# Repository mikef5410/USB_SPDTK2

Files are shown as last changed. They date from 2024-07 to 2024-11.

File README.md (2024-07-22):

## USB_SPDTK (KiCAD)

USB control of two standard microwave SPDT coax switches. This is the KiCAD re-work for JLCPCB assembly.

Related projects: [my USB Dual SPDT project](https://github.com/mikef5410/USB_SPDT)  and  [the software for these projects](https://github.com/mikef5410/USB_Attenuator_Switch_Stacklight)

# Project setup

The software is included here as a git submodule. After cloning, do a
`git submodule init` followed by `git submodule update --recursive`

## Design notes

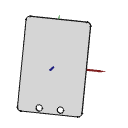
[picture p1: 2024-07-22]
thumbnails/Thumbnail.png

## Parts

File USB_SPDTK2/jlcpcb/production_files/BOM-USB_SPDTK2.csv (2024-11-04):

Comment | Designator | Footprint | LCSC | Quantity
4.7u | C19,C5,C7 | C_0402_1005Metric_Pad0.74x0.62mm_HandSolder | C106859 | 3
MMZ1608Y102B | FB1 | C_0603_1608Metric_Pad1.08x0.95mm_HandSolder | C114771 | 1
SW_Push | SW1,SW2 | SW_Tactile_SPST_NO_Straight_CK_PTS636Sx25SMTRLFS | C118141 | 2
13.3k | R5 | R_0402_1005Metric_Pad0.72x0.64mm_HandSolder | C122547 | 1
GRN | D7 | LED_0603_1608Metric_Pad1.05x0.95mm_HandSolder | C125094 | 1
22uF | C21 | C_1206_3216Metric_Pad1.33x1.80mm_HandSolder | C12891 | 1
LP2985-3.3 | U2 | SOT-23-5 | C129375 | 1
USB_B_Micro | J1 | USB_Micro-B_Amphenol_10118193-0001LF_Horizontal | C132562 | 1
1u | C1,C14,C15,C4 | C_0603_1608Metric_Pad1.08x0.95mm_HandSolder | C15849 | 4
220p | C2 | C_0402_1005Metric_Pad0.74x0.62mm_HandSolder | C1603 | 1
30pF | C17,C18 | C_0402_1005Metric_Pad0.74x0.62mm_HandSolder | C1658 | 2
10u | L1 | L_Changjiang_FNR4030S | C167879 | 1
0 | R2,R6 | R_0402_1005Metric_Pad0.72x0.64mm_HandSolder | C17168 | 2
4.7u | C3 | C_0805_2012Metric_Pad1.18x1.45mm_HandSolder | C1779 | 1
L293DD | U3 | SO-20_12.8x7.5mm_P1.27mm | C21610 | 1
100 | R11,R13,R14,R15,R17,R18,R9 | R_0402_1005Metric_Pad0.72x0.64mm_HandSolder | C25076 | 7
10k | R10,R12,R7,R8 | R_0402_1005Metric_Pad0.72x0.64mm_HandSolder | C25744 | 4
118k | R4 | R_0402_1005Metric_Pad0.72x0.64mm_HandSolder | C25748 | 1
PRTR5V0U2X | D2 | SOT-143 | C2827688 | 1
LM27313XMF | U1 | SOT-23-5 | C341750 | 1
93LC66AT-IOT | U5 | SOT-23-6 | C511344 | 1
0.1u | C10,C11,C12,C13,C16,C20,C6,C8,C9 | C_0402_1005Metric_Pad0.74x0.62mm_HandSolder | C5142567 | 9
16M 20pF 3225 | Y1 | Crystal_SMD_3225-4Pin_3.2x2.5mm_HandSoldering | C524727 | 1
RED | D3,D4,D5,D6 | LED_0603_1608Metric_Pad1.05x0.95mm_HandSolder | C84263 | 4
SS34 | D1 | D_SMA | C8678 | 1
STM32F411RETx | U4 | LQFP-64_10x10mm_P0.5mm | C94355 | 1
Conn_02x08_Odd_Even | J3 | PinHeader_2x08_P1.27mm_Vertical |  | 1

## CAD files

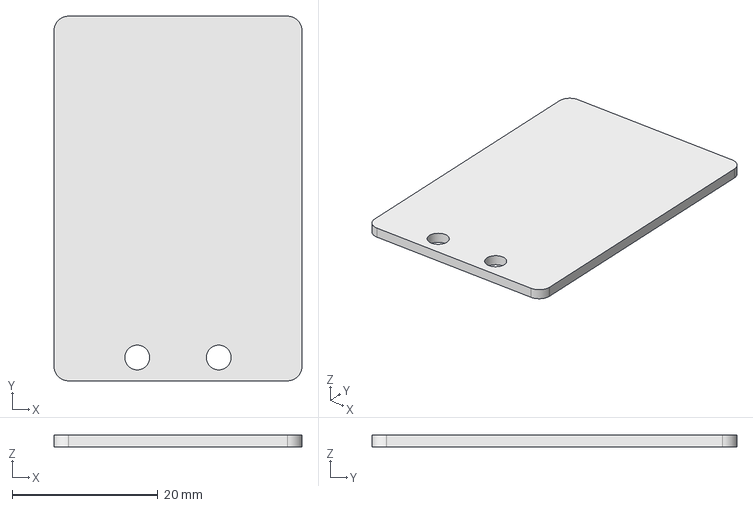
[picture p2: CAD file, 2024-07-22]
pcb_blank.FCStd
34.0 x 50.0 x 1.60 mm

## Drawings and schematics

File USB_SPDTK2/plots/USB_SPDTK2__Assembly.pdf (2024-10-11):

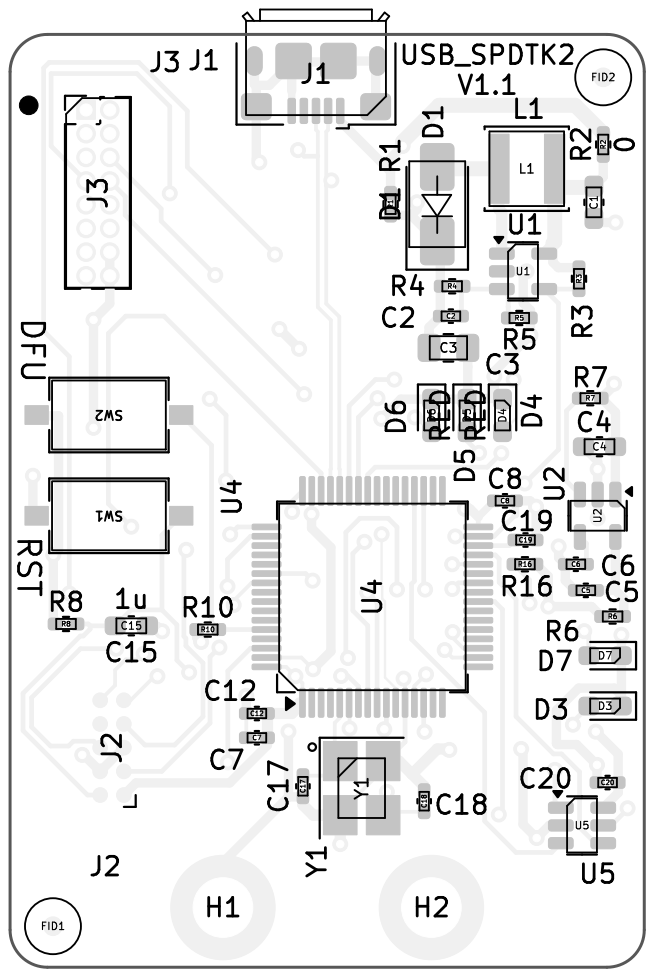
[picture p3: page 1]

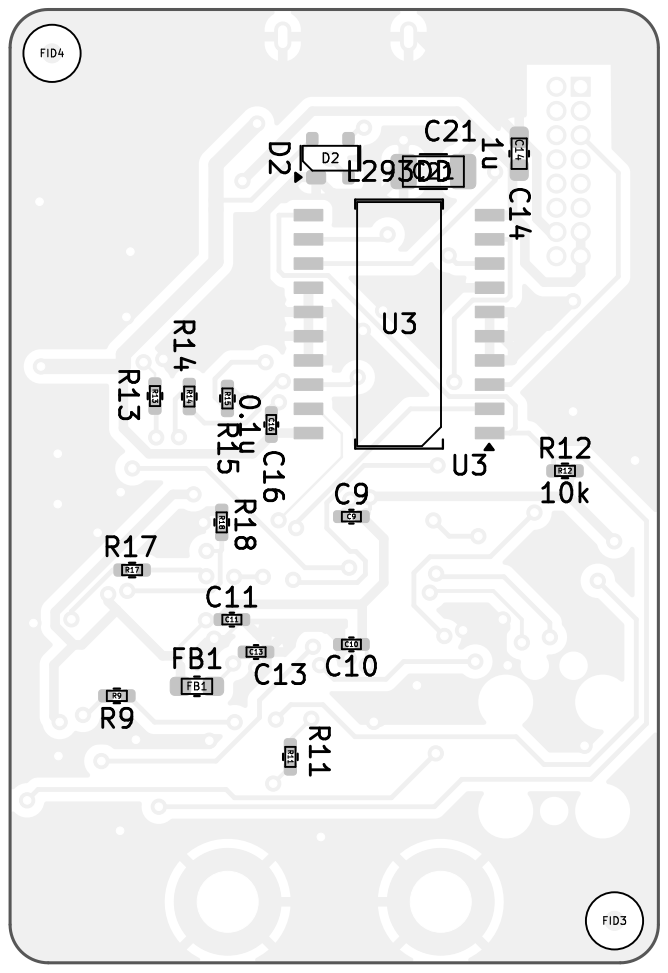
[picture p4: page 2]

Id: 1/1 Title: File: USB_SPDTK2.kicad_pcb Sheet:

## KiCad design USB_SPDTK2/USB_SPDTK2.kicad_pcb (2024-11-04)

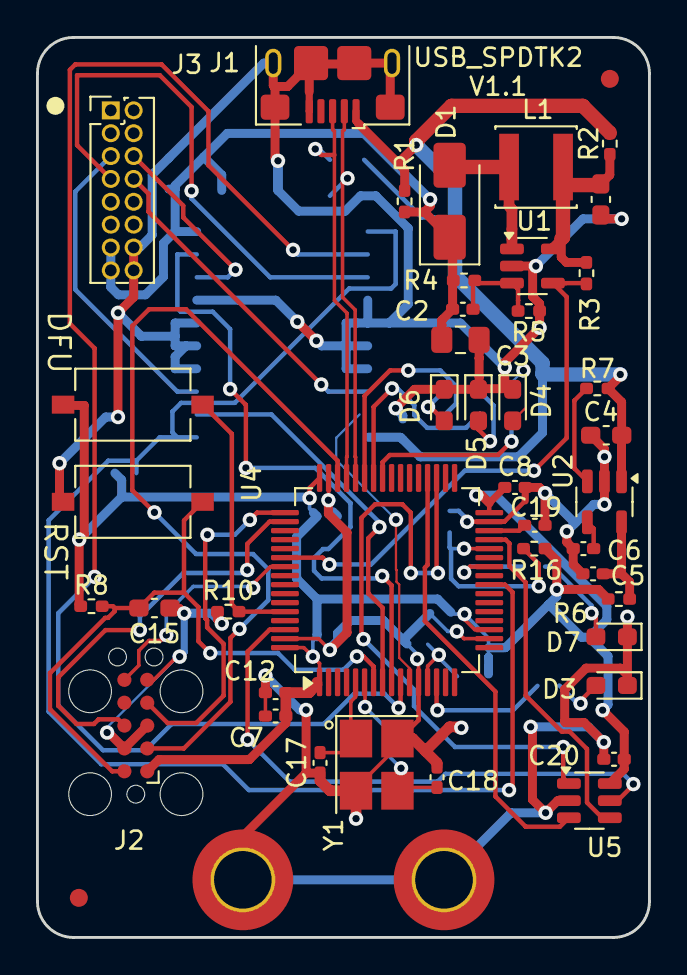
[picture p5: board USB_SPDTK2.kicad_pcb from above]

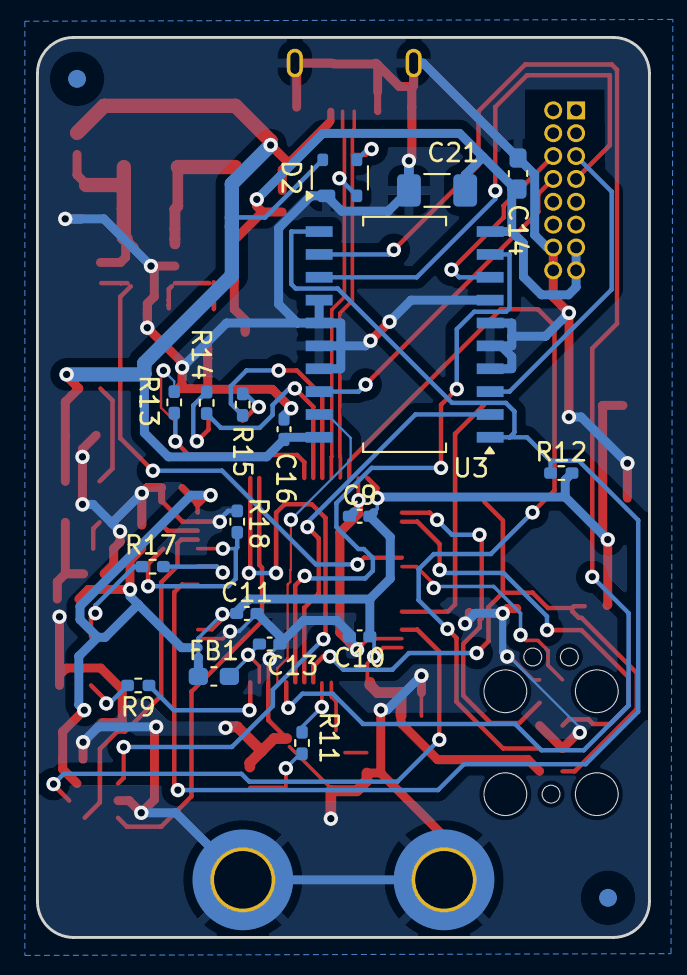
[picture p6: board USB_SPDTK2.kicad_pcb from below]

Board: 2 copper layers, 34.0 x 50.0 mm, 65 parts (20 on the bottom side), 48 nets.

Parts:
C1, C4, C14, C15: 1u; C_0603_1608Metric_Pad1.08x0.95mm_HandSolder
C2: 220p; C_0402_1005Metric_Pad0.74x0.62mm_HandSolder
C3: 4.7u; C_0805_2012Metric_Pad1.18x1.45mm_HandSolder
C5, C7, C19: 4.7u; C_0402_1005Metric_Pad0.74x0.62mm_HandSolder
C6, C8, C9, C10, C11, C12, C13, C16, C20: 0.1u; C_0402_1005Metric_Pad0.74x0.62mm_HandSolder
C17, C18: 30pF; C_0402_1005Metric_Pad0.74x0.62mm_HandSolder
C21: 22uF; C_1206_3216Metric_Pad1.33x1.80mm_HandSolder
D1: SS34; D_SMA
D2: PRTR5V0U2X; SOT-143
D3, D4, D5, D6: RED; LED_0603_1608Metric_Pad1.05x0.95mm_HandSolder
D7: GRN; LED_0603_1608Metric_Pad1.05x0.95mm_HandSolder
FB1: MMZ1608Y102B; C_0603_1608Metric_Pad1.08x0.95mm_HandSolder
FID1, FID2, FID3, FID4: Fiducial; Fiducial_1mm_Mask3mm
H1, H2: MountingHole_Pad; MountingHole_3.2mm_M3_DIN965_Pad_TopBottom
J1: USB_B_Micro; USB_Micro-B_Amphenol_10118193-0001LF_Horizontal
J2: TagConnectTC2050; Tag-Connect_TC2050-IDC-FP_2x05_P1.27mm_Vertical
J3: Conn_02x08_Odd_Even; PinHeader_2x08_P1.27mm_Vertical
L1: 10u; L_Changjiang_FNR4030S
R1, R2, R6: 0; R_0402_1005Metric_Pad0.72x0.64mm_HandSolder
R3, R7, R8, R10, R12, R16: 10k; R_0402_1005Metric_Pad0.72x0.64mm_HandSolder
R4: 118k; R_0402_1005Metric_Pad0.72x0.64mm_HandSolder
R5: 13.3k; R_0402_1005Metric_Pad0.72x0.64mm_HandSolder
R9, R11, R13, R14, R15, R17, R18: 100; R_0402_1005Metric_Pad0.72x0.64mm_HandSolder
SW1, SW2: SW_Push; SW_Tactile_SPST_NO_Straight_CK_PTS636Sx25SMTRLFS
U1: LM27313XMF; SOT-23-5
U2: LP2985-3.3; SOT-23-5
U3: L293DD; SO-20_12.8x7.5mm_P1.27mm
U4: STM32F411RETx; LQFP-64_10x10mm_P0.5mm
U5: 93LC66AT-IOT; SOT-23-6
Y1: 16M 20pF 3225; Crystal_SMD_3225-4Pin_3.2x2.5mm_HandSoldering

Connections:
+3.3V: C7.1, C8.1, C9.2, C10.1, C11.1, C12.2, C20.2, FB1.1, J2.1 (VTref), R6.2, R8.1, R12.2, R16.1, SW2.2, U4.1 (VBAT), U4.19 (VDD), U4.32 (VDD), U4.48 (VDD), U4.64 (VDD), U5.6 (Vcc)
+VSW: C2.1, C3.2, C14.2, C21.1, D1.1 (K), J3.13, J3.15, R1.2, R4.2, U3.10 (VCC2)
/Controller/BOOT1: R16.2, R18.1, U4.28 (PB2)
/Controller/JTCK: J2.4 (SWCLK/TCK), U4.49 (PA14)
/Controller/JTDI: J2.8 (NC/TDI), U4.50 (PA15)
/Controller/JTDO: J2.6 (SWO/TDO), U4.55 (PB3)
/Controller/JTMS: J2.2 (SWDIO/TMS), U4.46 (PA13)
/Controller/SPI2_MISO: U4.35 (PB14), U5.1 (DO)
/Controller/SPI2_MOSI: U4.36 (PB15), U5.3 (DI)
/Controller/SPI2_SCK: U4.29 (PB10), U5.4 (CLK)
/Controller/USB+: D2.3 (I/O2), J1.3 (D+), U4.45 (PA12)
/Controller/USB-: D2.2 (I/O1), J1.2 (D-), U4.44 (PA11)
/Controller/~SPI2NSS: U4.62 (PB9), U5.5 (CS)
GND: C1.1, C3.1, C4.1, C5.1, C6.1, C7.2, C8.2, C9.1, C10.2, C11.2, C12.1, C13.2, C14.1, C15.1, C16.1, C17.2, C18.2, C19.1, C20.1, C21.2, D2.1 (GND), D3.1 (K), D4.1 (K), D5.1 (K), D6.1 (K), D7.1 (K), H1.1, H2.1, J1.5 (GND), J1.6 (Shield), J2.3 (GND), J2.5 (GND), J2.9 (GNDDetect), J3.14, J3.16, R5.1, R10.1, R18.2, SW1.2, U1.2 (GND), U2.2 (GND), U3.4 (GND), U3.5 (GND), U3.6 (GND), U3.7 (GND), U3.14 (GND), U3.15 (GND), U3.16 (GND), U3.17 (GND), U4.12 (VSSA), U4.18 (VSS), U4.31 (VSS), U4.47 (VSS), U4.63 (VSS), U5.2 (Vss), Y1.2, Y1.4
HVEnable: R3.1, U1.4 (EN), U4.54 (PD2)
unnamed: C18.1, R11.1, Y1.3
unnamed: D1.2 (A), L1.2, U1.1 (SW)
unnamed: D3.2 (A), R9.2
unnamed: D4.2 (A), R13.2
unnamed: D5.2 (A), R14.2
unnamed: D6.2 (A), R15.2
unnamed: D7.2 (A), R17.2
unnamed: C15.2, J2.10 (~RESET), R8.2, SW1.1, U4.7 (NRST)
unnamed: C2.2, R4.1, R5.2, U1.3 (FB)
unnamed: C1.2, L1.1, R2.1, R3.2, U1.5 (VIN)
unnamed: C6.2, U2.4 (BP)
unnamed: R7.2, U2.3 (ON/~OFF)
unnamed: C5.2, R6.1, U2.5 (VOUT)
unnamed: R10.2, SW2.1, U4.60 (BOOT0)
unnamed: R9.1, U4.14 (PA0)
unnamed: R13.1, U4.41 (PA8)
unnamed: R14.1, U4.42 (PA9)
unnamed: R15.1, U4.43 (PA10)
unnamed: R17.1, U4.26 (PB0)
unnamed: C17.1, U4.5 (PH0), Y1.1
unnamed: R11.2, U4.6 (PH1)
unnamed: C19.2, U4.30 (VCAP1)
unnamed: C13.1, FB1.2, U4.13 (VDDA)
S1D: U3.9 (2A), U4.9 (PC1)
S1D_OUT: J3.6, U3.8 (2Y)
S1U: U3.2 (1A), U4.8 (PC0)
S1U_OUT: J3.5, U3.3 (1Y)
S2D: U3.19 (4A), U4.11 (PC3)
S2D_OUT: J3.8, U3.18 (4Y)
S2U: U3.12 (3A), U4.10 (PC2)
S2U_OUT: J3.7, U3.13 (3Y)
SW_Enable: R12.1, U3.1 (EN1,2), U3.11 (EN3,4), U4.24 (PC4)
VBUS: C4.2, C16.2, D2.4 (VCC), J1.1 (VBUS), R1.1, R2.2, R7.1, U2.1 (VIN), U3.20 (VCC1)

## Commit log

2024-08-01 Add do not fab warnings. L293D pinout is incorrect.
    [Controller.kicad_sch, USB_SPDTK2.kicad_pcb]
2024-10-08 Update to v1.1, fix incorrect footprint for L293DD
    [BOM-USB_SPDTK2.csv, Controller.kicad_sch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]
2024-10-11 Fix connector and C21 interference.
    [CPL-USB_SPDTK2.csv, USB_SPDTK2-CuBottom.gbr, USB_SPDTK2-CuTop.gbr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]
2024-11-04 Submitted to JLCPCB. Needed an in-stock part for D7
    [BOM-USB_SPDTK2.csv, Controller.kicad_sch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]
